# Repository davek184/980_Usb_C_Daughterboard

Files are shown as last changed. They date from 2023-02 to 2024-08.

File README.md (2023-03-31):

Replacement USB-C daughterboard for Leopold FC980c/FC980m, can be used with the stock case or Norbauer Heavy-9.

Uses Qwiic / JST SH or Pico-EZmate connector.

_Note stock Leopold case requires filing USB opening and cable is tight._

Related project [FC980c controller](https://github.com/davek184/fc980c-controller)

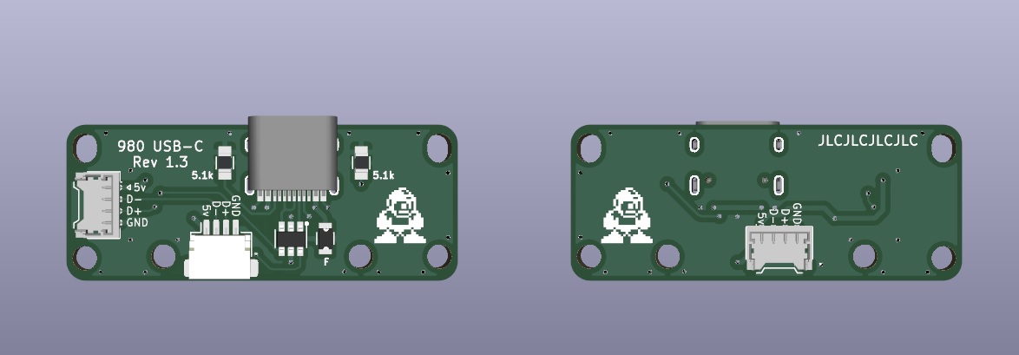
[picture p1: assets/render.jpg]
render


## Revision 1.3
- Added Molex Pico-Ezmate connector option.  Note there are 2 of these one on the back that is optional.

## BOM

| LCSC part # | Description | Value | Package  | Amount |
| --- | --- | ----- | --- | ---:|
| C165948 | USB | | SMD/TH | 1 |
| C160404 | Connector | | SMD | 1 |
| C528030 | Connector | | SMD | 1 |
| C261942 | Fuse	 | | SMD | 1 |
| C27834 | Resistor | 5.1 | SMD | 2 |
| C7519 | ESD | | SMD | 1 |
| C528030 | Connector | | SMD | 2 | 

## Cable

This daughterboard uses a different connector then the OEM one. Suggest starting with an [Adafruit 4424 cable](https://www.adafruit.com/product/4424) so no crimping needs to be done. 

cable

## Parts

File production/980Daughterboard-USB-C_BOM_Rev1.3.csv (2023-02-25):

Designator | Footprint | Quantity | Value | LCSC Part #
F | F_0805 | 1 | Polyfuse_Small | C261942
J1 | HRO-TYPE-C-31-M-12 | 1 | TYPE-C-31-M-12 | C165948
J2 | JST_SH_SM04B-SRSS-TB_1x04-1MP_P1.00mm_Horizontal | 1 | ai03_ud | C160404
J3, J4 | Molex_Pico-EZmate_78171-0004_1x04-1MP_P1.20mm_Vertical | 2 | Molex_Pico-EZmate_78171-0004_1x04-1MP_P1.20mm_Vertical | C528030
R1, R2 | R_0805 | 2 | 5.1k | C27834
U1 | USBLC6-2SC6 | 1 | USBLC6-2SC6 | C7519

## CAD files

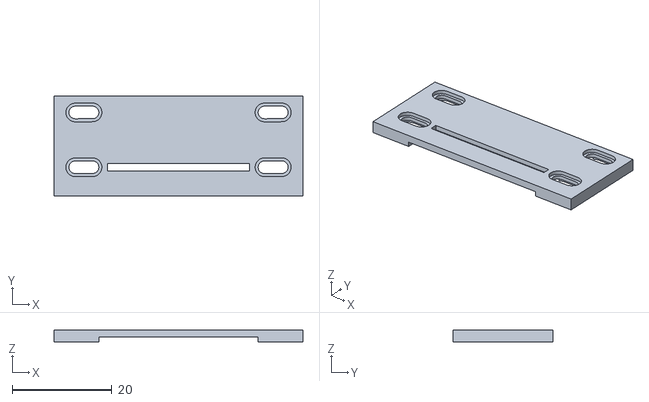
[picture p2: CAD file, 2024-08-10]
assets/USB_C_Holder_2mm_with_PCB_cutout_v3.stl
50.0 x 20.0 x 2.50

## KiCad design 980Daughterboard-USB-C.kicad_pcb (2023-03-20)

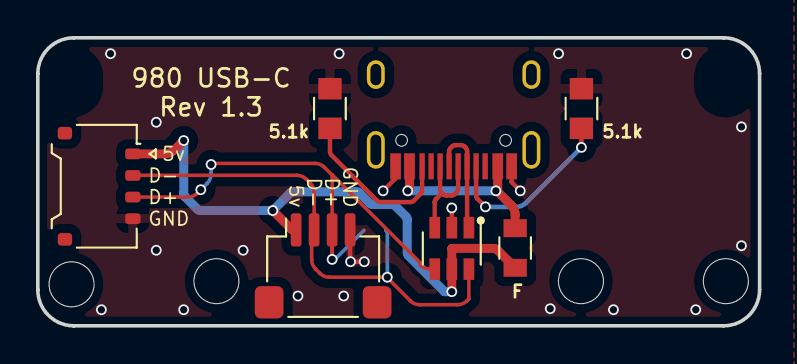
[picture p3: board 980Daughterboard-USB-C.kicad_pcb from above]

Board: 2 copper layers, 40.1 x 16.0 mm, 8 parts (1 on the bottom side), 8 nets.

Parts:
F: Polyfuse_Small; F_0805
J1: TYPE-C-31-M-12; HRO-TYPE-C-31-M-12
J2: ai03_ud; JST_SH_SM04B-SRSS-TB_1x04-1MP_P1.00mm_Horizontal
J3, J4: Molex_Pico-EZmate_78171-0004_1x04-1MP_P1.20mm_Ver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; Molex_Pico-EZmate_78171-0004_1x04-1MP_P1.20mm_Vertical
R1, R2: 5.1k; R_0805
U1: USBLC6-2SC6

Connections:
D+: J2.3, J3.3, J4.3, U1.4 (I/O2)
D-: J2.2, J3.2, J4.2, U1.6 (I/O1)
GND: J1.1 (GND), J1.12 (GND), J2.4, J3.4, J4.4, R1.2, R2.2, U1.2 (GND)
unnamed: J1.4 (CC1), R2.1
unnamed: J1.5 (DN2), J1.7 (DN1), U1.1 (I/O1)
unnamed: J1.6 (DP1), J1.8 (DP2), U1.3 (I/O2)
unnamed: J1.10 (CC2), R1.1
VBUS: F.1, F.2, J1.2 (VBUS), J1.11 (VBUS), J2.1, J3.1, J4.1, U1.5 (VBUS)

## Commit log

2023-02-25 Rev 1.3
    1.3 includes pico ezmate connector. There is also an additional connector on the back for the stock case.
    [980Daughterboard-USB-C.kicad_pcb, 980Daughterboard-USB-C.kicad_sch, 980Daughterboard-USB-C_BOM_Rev1.3.csv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]
2024-08-10 Alt option from Tinster4x4
    [USB_C_Holder_2mm_with_PCB_cutout_v3.stl]
